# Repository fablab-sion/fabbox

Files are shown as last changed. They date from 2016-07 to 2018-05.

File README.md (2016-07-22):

# fabbox
Petit coffre fort à construire avec les moyens d'un Fablab!

<br />Cette œuvre est mise à disposition selon les termes de la <a rel="license" href="http://creativecommons.org/licenses/by-sa/4.0/">Licence Creative Commons Attribution -  Partage dans les Mêmes Conditions 4.0 International</a>.

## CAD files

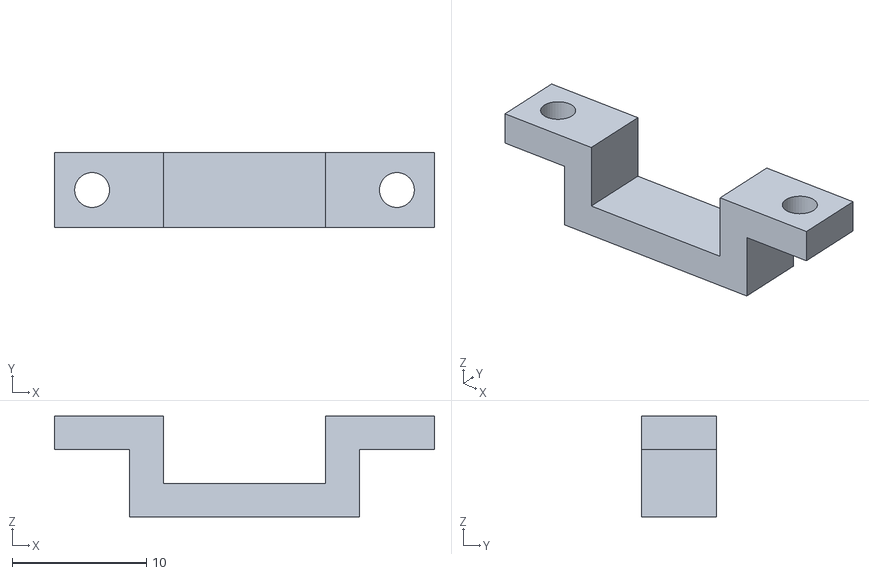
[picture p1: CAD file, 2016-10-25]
3d/CoilHolder.stl
28.3 x 5.60 x 7.50

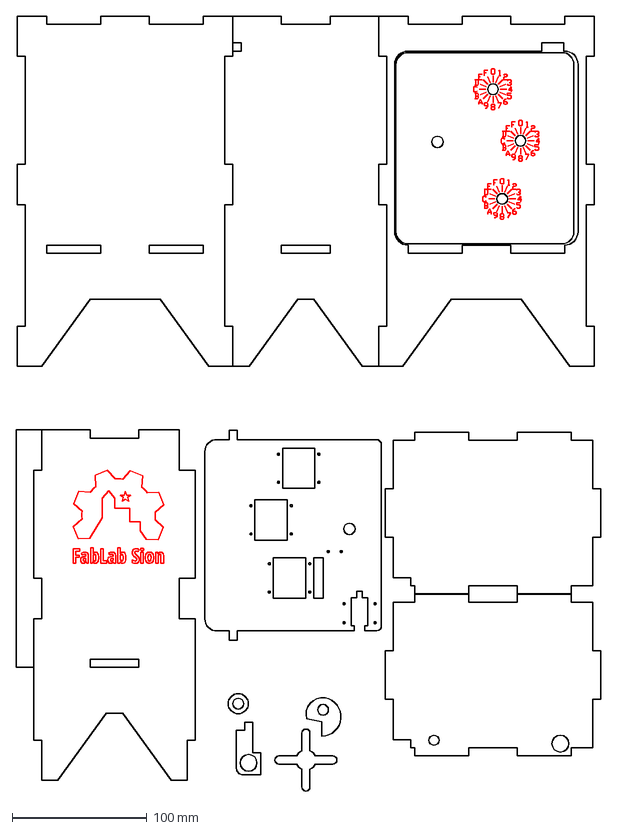
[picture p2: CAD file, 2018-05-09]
laser/fabbox.dxf
433.7 x 574.9 mm

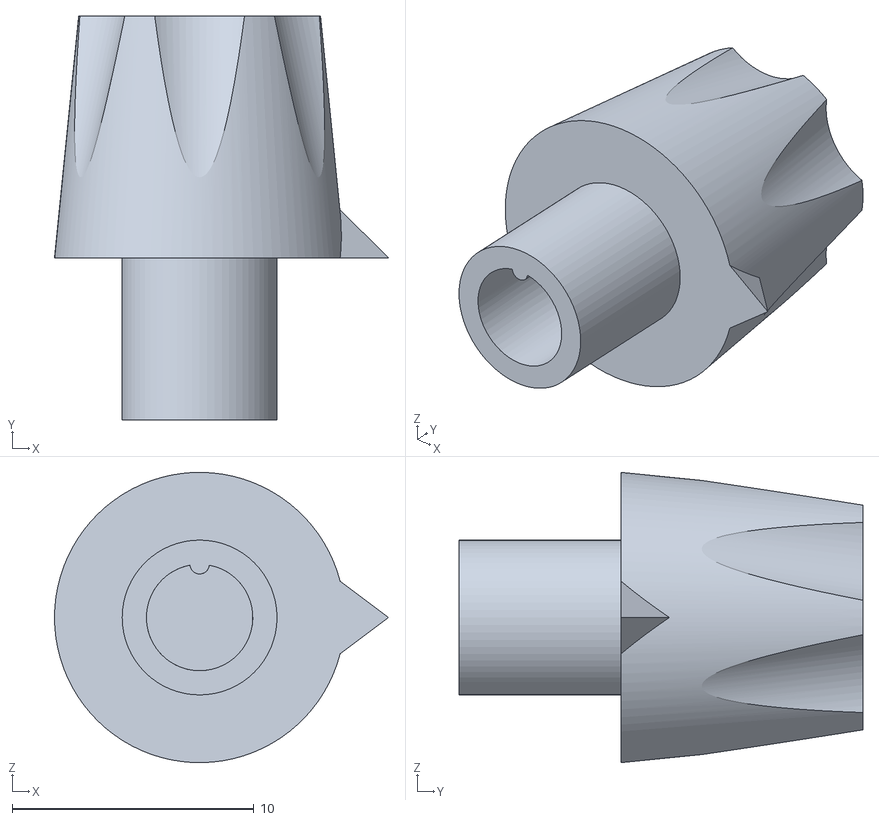
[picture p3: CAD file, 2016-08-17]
3d/Bouton.stl
13.8 x 16.7 x 12.0

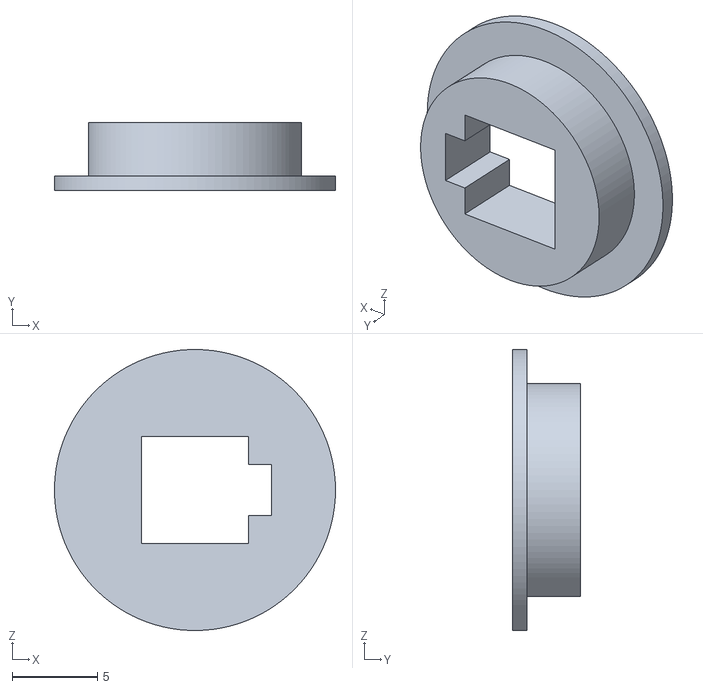
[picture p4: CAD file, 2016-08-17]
3d/Charniere.stl
16.5 x 4.00 x 16.5

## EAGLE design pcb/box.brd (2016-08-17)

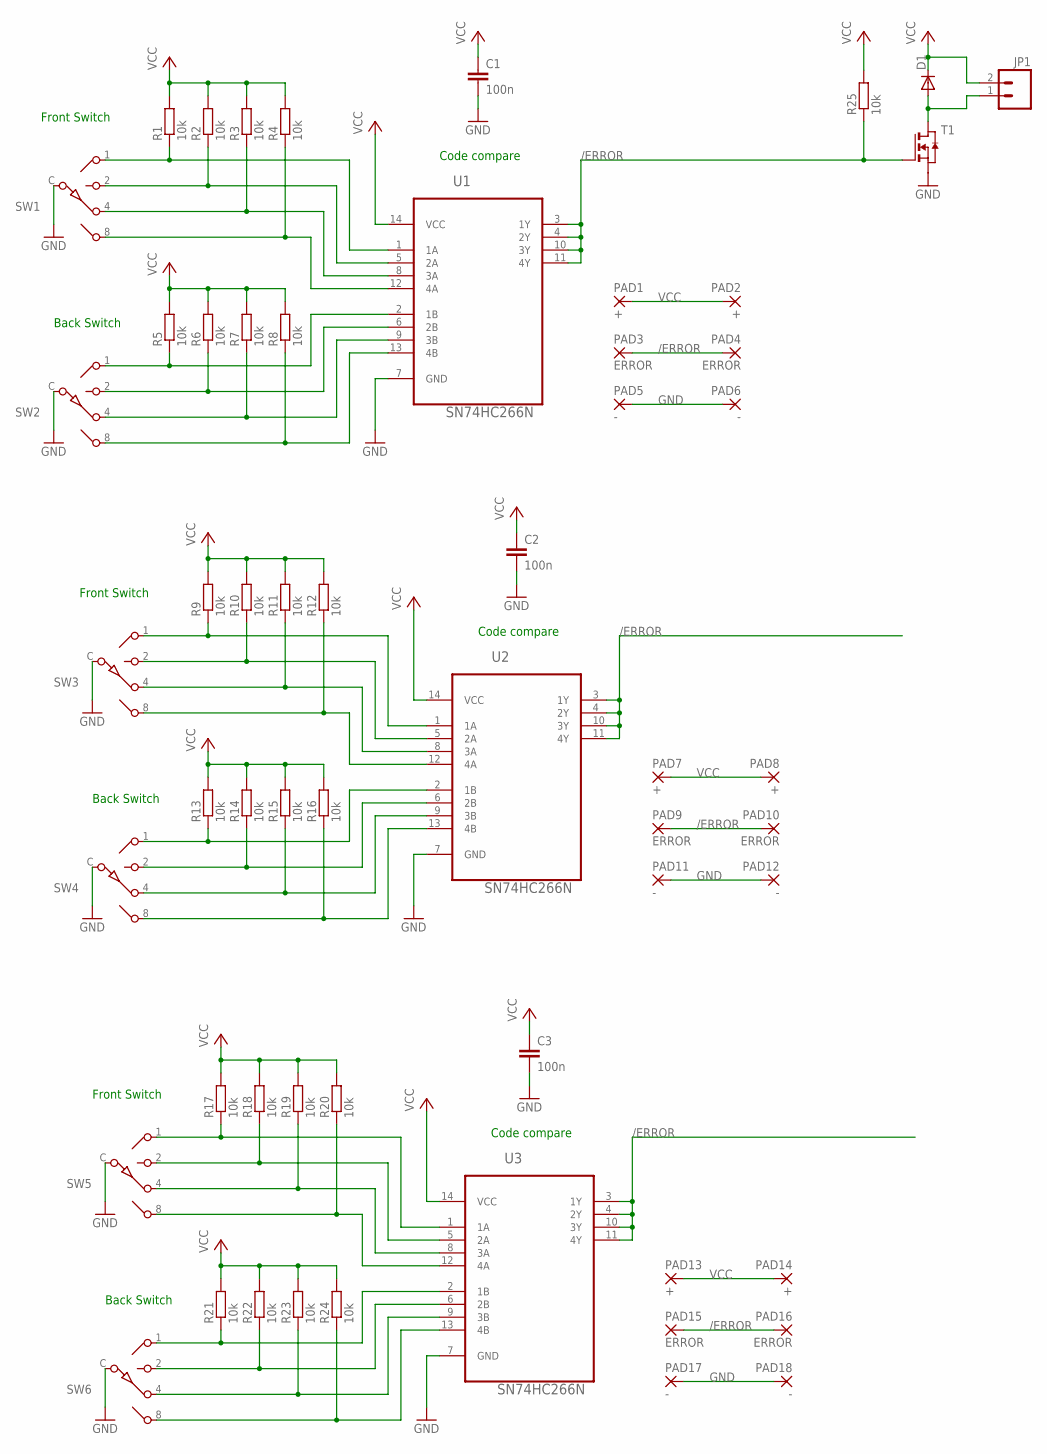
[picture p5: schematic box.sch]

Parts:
C1, C2, C3: 100n; C0805
D1: DIODE-DO41-7.6; DO41-7.6
JP1: M02JST-PTH-2; JST-2-PTH
PAD1, PAD2, PAD7, PAD8, PAD13, PAD14: +; 2,15/1,0
PAD3, PAD4, PAD9, PAD10, PAD15, PAD16: ERROR; 2,15/1,0
PAD5, PAD6, PAD11, PAD12, PAD17, PAD18: -; 2,15/1,0
R1, R2, R3, R4, R5, R6, R7, R8, R9, R10, R11, R12, R13, R14, R15, R16, R17, R18, R19, R20, R21, R22, R23, R24, R25: 10k; R0805
SW1, SW2, SW3, SW4, SW5, SW6: ROTARY-SWITCH-10POSMCRM4HAF-10R-V-B; MCRM4HAF
T1: TSM3442; SOT23-6
U1, U2, U3: SN74HC266N; DIP254P762X508-14

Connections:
/ERROR: PAD3.1, PAD4.1, PAD9.1, PAD10.1, PAD15.1, PAD16.1, R25.1, T1.3 (G), U1.3 (1Y), U1.4 (2Y), U1.10 (3Y), U1.11 (4Y), U2.3 (1Y), U2.4 (2Y), U2.10 (3Y), U2.11 (4Y), U3.3 (1Y), U3.4 (2Y), U3.10 (3Y), U3.11 (4Y)
GND: C1.2, C2.2, C3.2, PAD5.1, PAD6.1, PAD11.1, PAD12.1, PAD17.1, PAD18.1, SW1.C, SW2.C, SW3.C, SW4.C, SW5.C, SW6.C, T1.4 (S), U1.7 (GND), U2.7 (GND), U3.7 (GND)
unnamed: R1.1, SW1.1, U1.1 (1A)
unnamed: R2.1, SW1.2, U1.5 (2A)
unnamed: R3.1, SW1.4, U1.8 (3A)
unnamed: R4.1, SW1.8, U1.12 (4A)
unnamed: D1.A, JP1.1, T1.1 (D), T1.2 (D), T1.5 (D), T1.6 (D)
unnamed: R5.1, SW2.1, U1.2 (1B)
unnamed: R6.1, SW2.2, U1.6 (2B)
unnamed: R7.1, SW2.4, U1.9 (3B)
unnamed: R8.1, SW2.8, U1.13 (4B)
unnamed: R9.1, SW3.1, U2.1 (1A)
unnamed: R10.1, SW3.2, U2.5 (2A)
unnamed: R11.1, SW3.4, U2.8 (3A)
unnamed: R12.1, SW3.8, U2.12 (4A)
unnamed: R13.1, SW4.1, U2.2 (1B)
unnamed: R14.1, SW4.2, U2.6 (2B)
unnamed: R15.1, SW4.4, U2.9 (3B)
unnamed: R16.1, SW4.8, U2.13 (4B)
unnamed: R17.1, SW5.1, U3.1 (1A)
unnamed: R18.1, SW5.2, U3.5 (2A)
unnamed: R19.1, SW5.4, U3.8 (3A)
unnamed: R20.1, SW5.8, U3.12 (4A)
unnamed: R21.1, SW6.1, U3.2 (1B)
unnamed: R22.1, SW6.2, U3.6 (2B)
unnamed: R23.1, SW6.4, U3.9 (3B)
unnamed: R24.1, SW6.8, U3.13 (4B)
VCC: C1.1, C2.1, C3.1, D1.C, JP1.2, PAD1.1, PAD2.1, PAD7.1, PAD8.1, PAD13.1, PAD14.1, R1.2, R2.2, R3.2, R4.2, R5.2, R6.2, R7.2, R8.2, R9.2, R10.2, R11.2, R12.2, R13.2, R14.2, R15.2, R16.2, R17.2, R18.2, R19.2, R20.2, R21.2, R22.2, R23.2, R24.2, R25.2, U1.14 (VCC), U2.14 (VCC), U3.14 (VCC)

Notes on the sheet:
Front Switch
Back Switch
Code compare

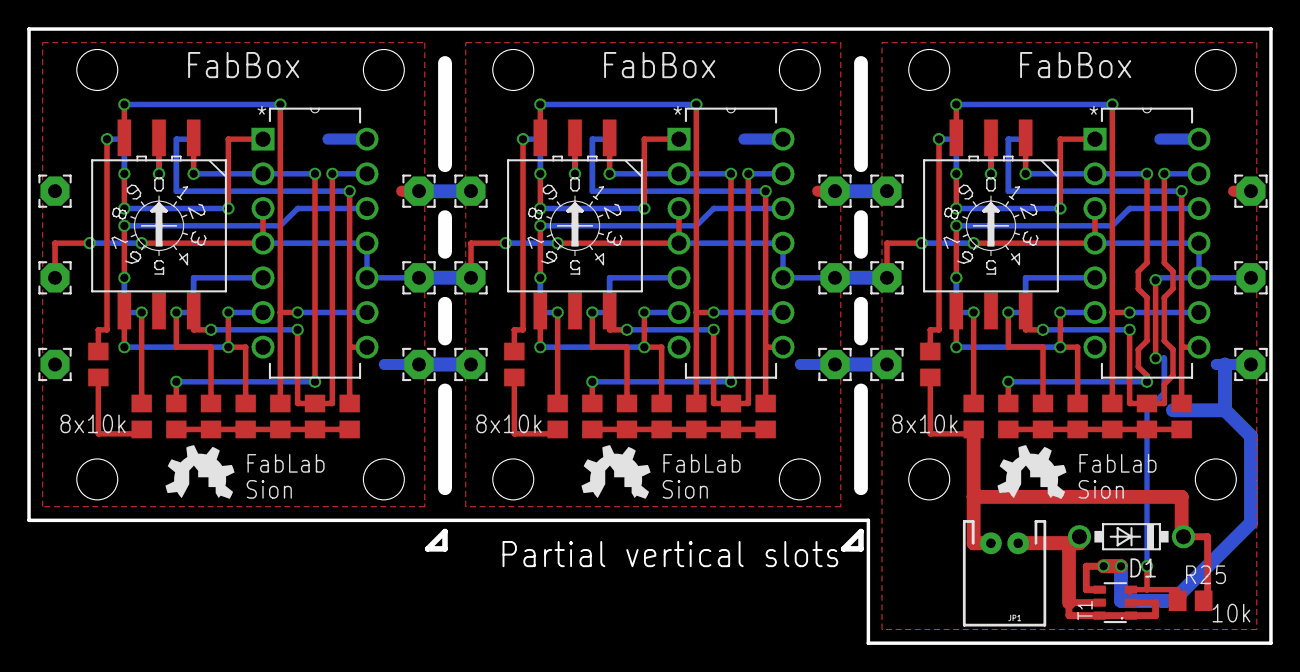
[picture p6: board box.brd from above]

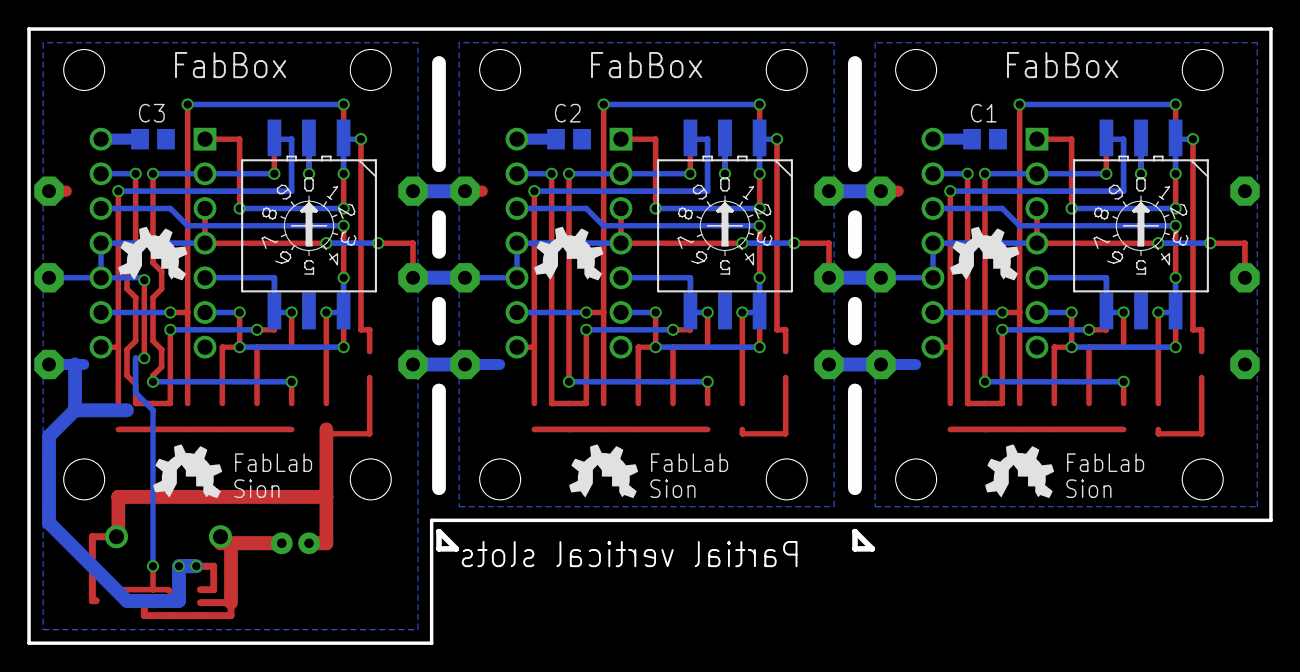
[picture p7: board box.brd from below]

Board: 2 copper layers, 91.0 x 45.0 mm, 67 parts (12 on the bottom side), 28 nets.

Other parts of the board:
E$1, E$3, E$5: LOGO_200
E$2, E$4, E$6: LOGO_200_TEXT
U$1, U$2, U$3: LOGO_200_TEXT

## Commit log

2016-08-17 Add pcb sources.
    [box.brd, box.sch]
2016-08-17 Add mechanicals.
    [Bouton.stl, Charniere.stl, FabBox_1.dxf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]
2016-10-25 Add coil holder.
    [CoilHolder.stl]
2018-05-09 Fix wrong dxfs.
    [FabBox_1.dxf, FabBox_2.dxf, fabbox.dxf]

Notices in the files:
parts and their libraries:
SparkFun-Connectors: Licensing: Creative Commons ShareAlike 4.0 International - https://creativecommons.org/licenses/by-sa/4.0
